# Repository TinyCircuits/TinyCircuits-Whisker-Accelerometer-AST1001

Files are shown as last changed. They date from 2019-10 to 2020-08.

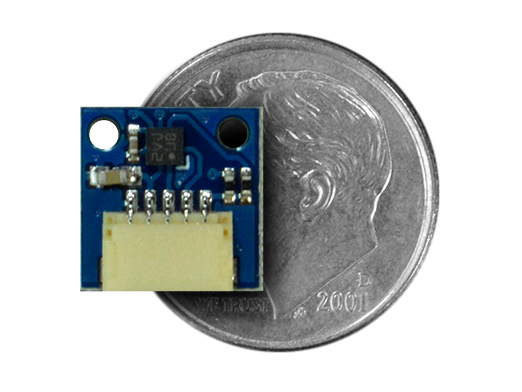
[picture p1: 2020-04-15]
images/AST1001-Product-Photo-03.png

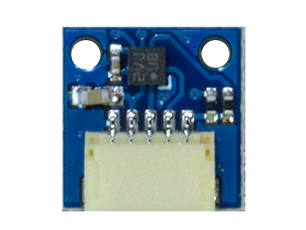
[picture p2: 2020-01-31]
images/AST1001-Learn-Photo-01.png

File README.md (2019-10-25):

# TinyCircuits Accelerometer Wireling Board
# AST1001 Rev1

The design files are located under design_files/ for the TinyCircuits ASD2205 Rev 2 PCB.  This is a Wireling board that has a BMA250 Accelerometer. 

Format is in Cadsoft Eagle format - Eagle version 6.2 was used for the original design.

For more infomation on this, check out the product page at TinyCircuits.com:  https://tinycircuits.com/products/microsd-tinyshield

# License:

Design by TinyCircuits.
All design files are released under the Creative Commons Attribution Share-Alike 3.0 License, see the following link for details: http://creativecommons.org/licenses/by-sa/3.0

All text above must be included in any redistribution or derived design

This project uses designs and concepts developed as part of the Arduino project and the LilyPad project.  The TinyCircuits design files themselves (schematics, PCB and libraries) are not directly derived from these works' design files and have been created new, however the concepts and basic architecture behind the TinyDuino and TinyLily products are derived and we thank the hard work of the organizations below for their contributions to open-source hardware:
  
Original Arduino Uno Design by Team Arduino

LilyPad Arduino Design by Leah Buechley and Sparkfun Electronics

Please support the open-source hardware community

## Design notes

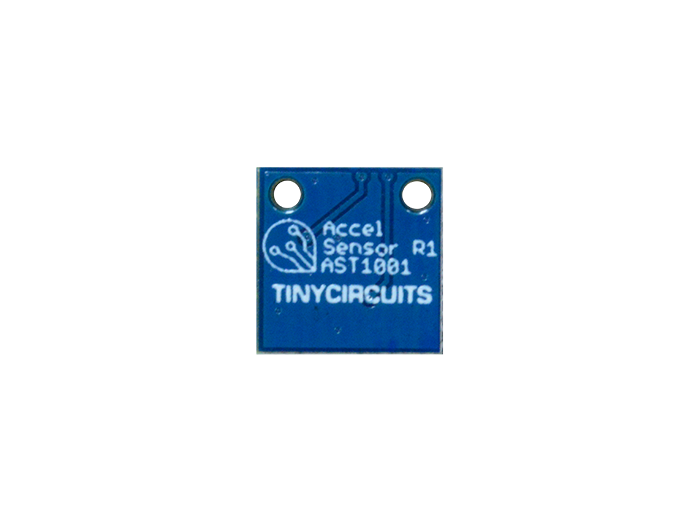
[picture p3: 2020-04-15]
images/AST1001-Product-Photo-02.png

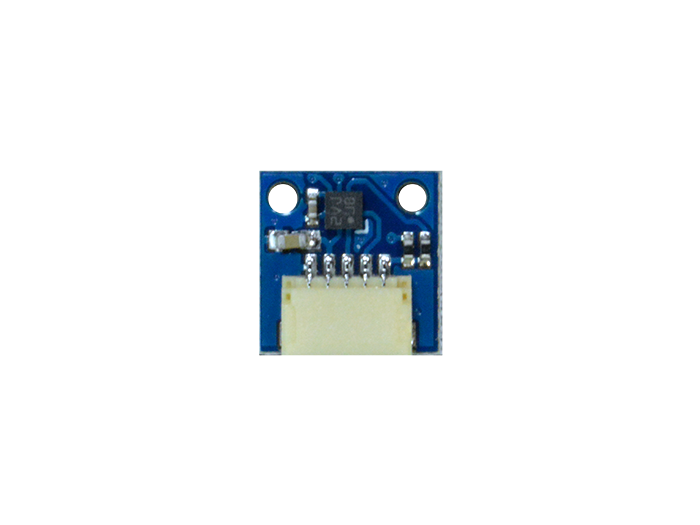
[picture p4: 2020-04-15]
images/AST1001-Product-Photo-01.png

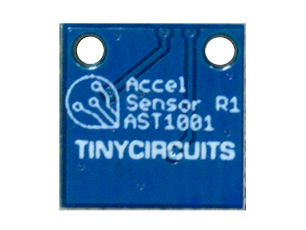
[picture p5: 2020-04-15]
images/AST1001-Learn-Photo-02.png

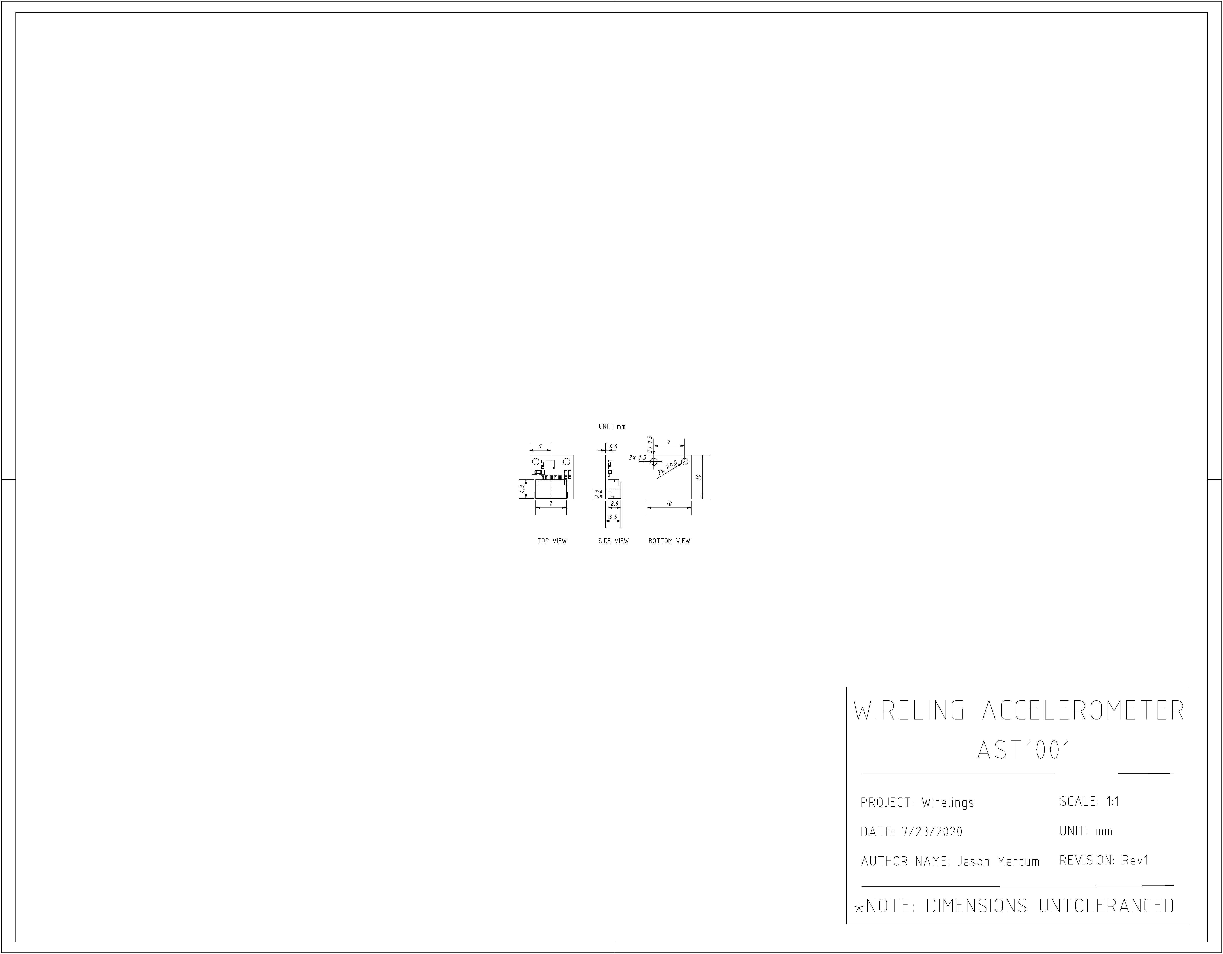
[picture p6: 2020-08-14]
cad/Wireling_ACCELEROMETER_AST1001_REV1-DETAILED_DRAWING-PNG.png

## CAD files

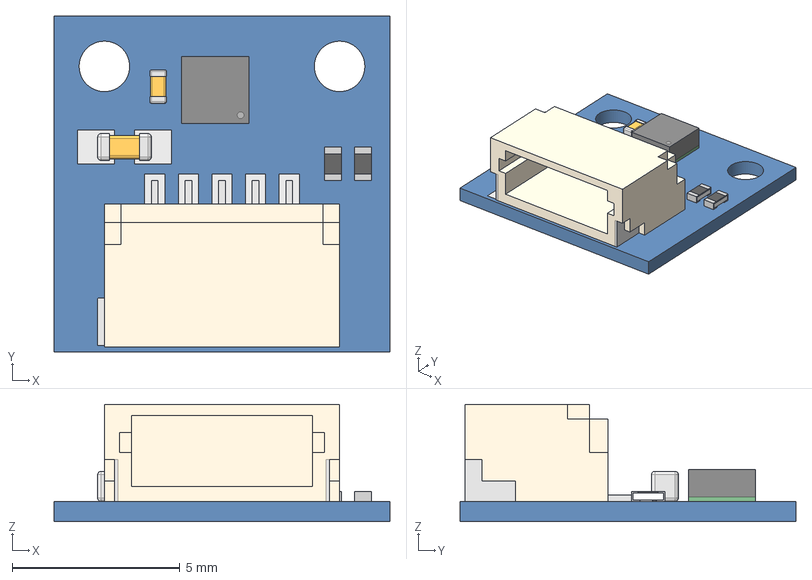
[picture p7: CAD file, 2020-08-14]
cad/Wireling_ACCELEROMETER_AST1001_REV1-STEP.step
10.0 x 10.0 x 3.50 mm

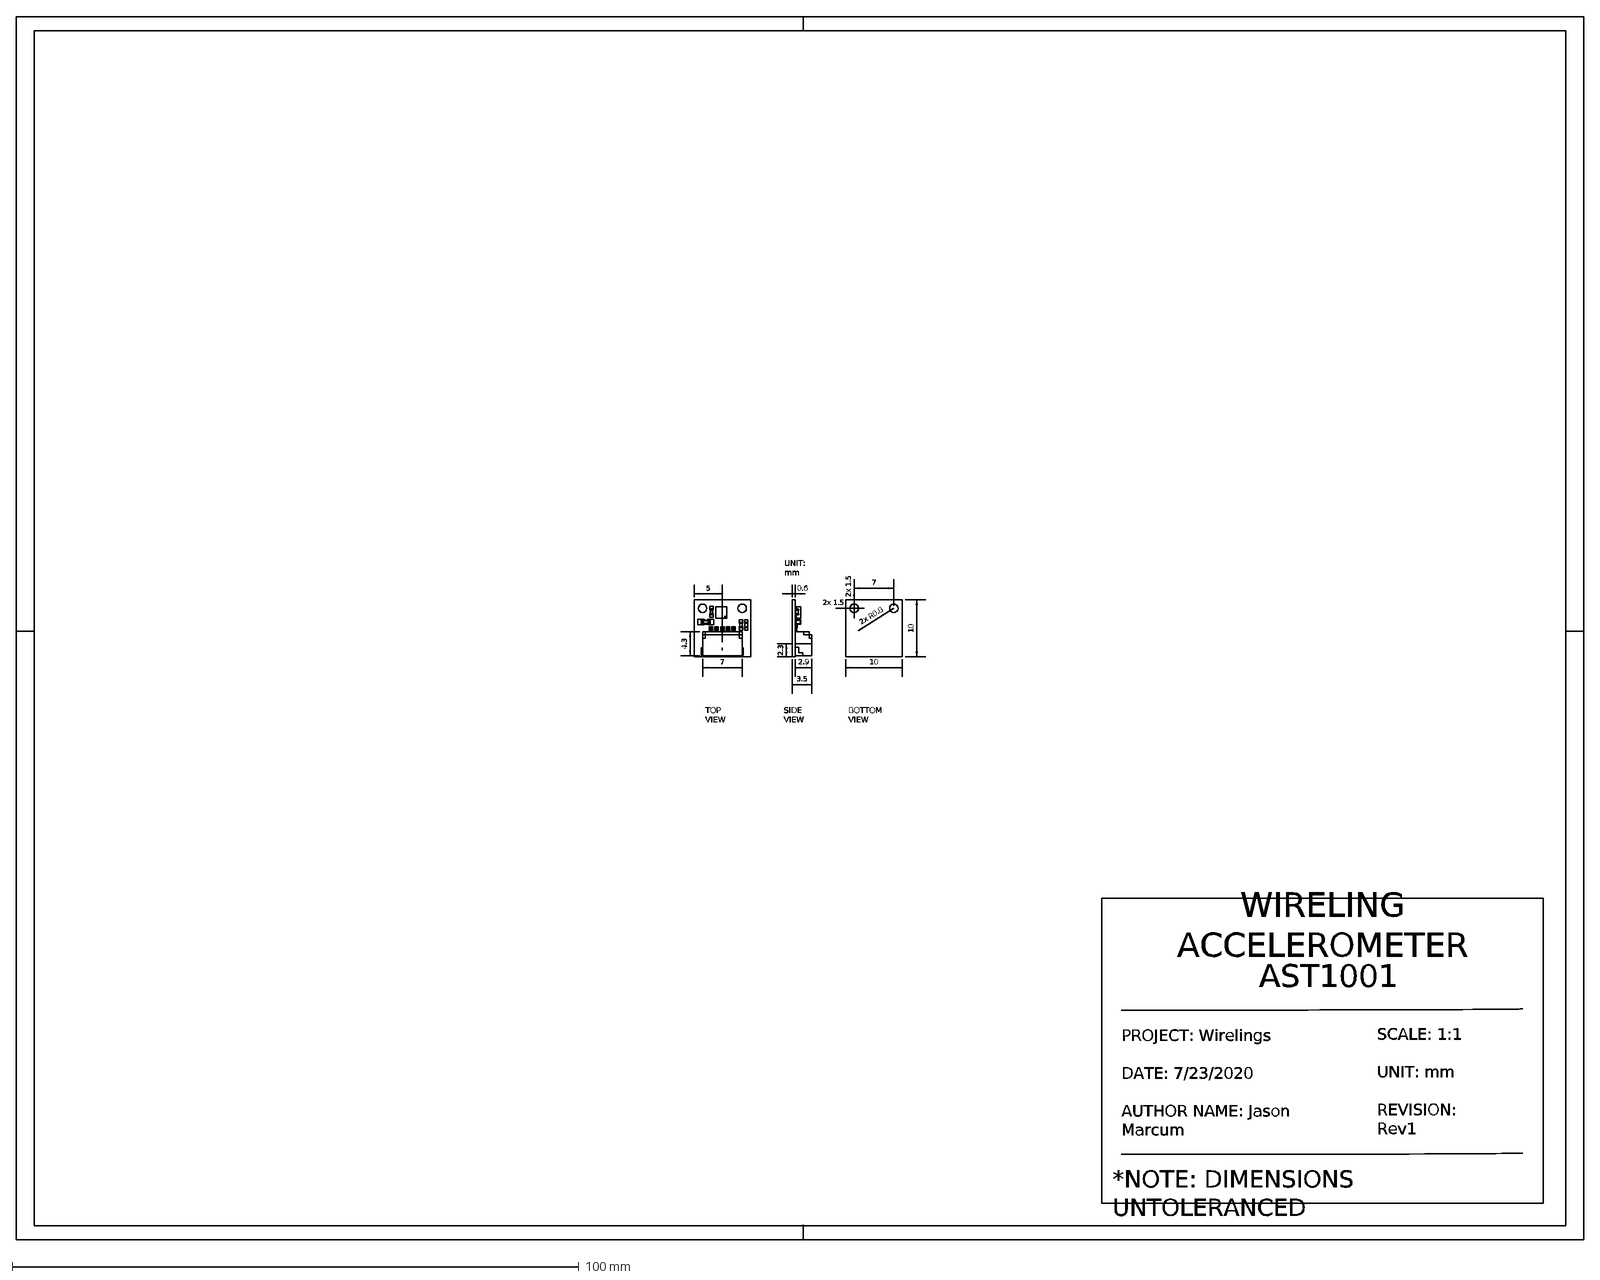
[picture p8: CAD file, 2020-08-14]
cad/Wireling_ACCELEROMETER_AST1001_REV1-DETAILED_DRAWING-DXF.dxf
*NOTE: DIMENSIONS UNTOLERANCED
WIRELING ACCELEROMETER
AST1001
SCALE: 1:1 UNIT: mm REVISION: Rev1
UNIT: mm
TOP VIEW
SIDE VIEW
BOTTOM VIEW
7
4.3
5
2.9
3.5
0.6
2.3
2x 1.5
2x R0.8
10
PROJECT: Wirelings DATE: 7/23/2020 AUTHOR NAME: Jason Marcum

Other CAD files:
cad/Wireling_ACCELEROMETER_AST1001_REV1-IGES.iges
cad/Wireling_ACCELEROMETER_AST1001_REV1-STL.stl

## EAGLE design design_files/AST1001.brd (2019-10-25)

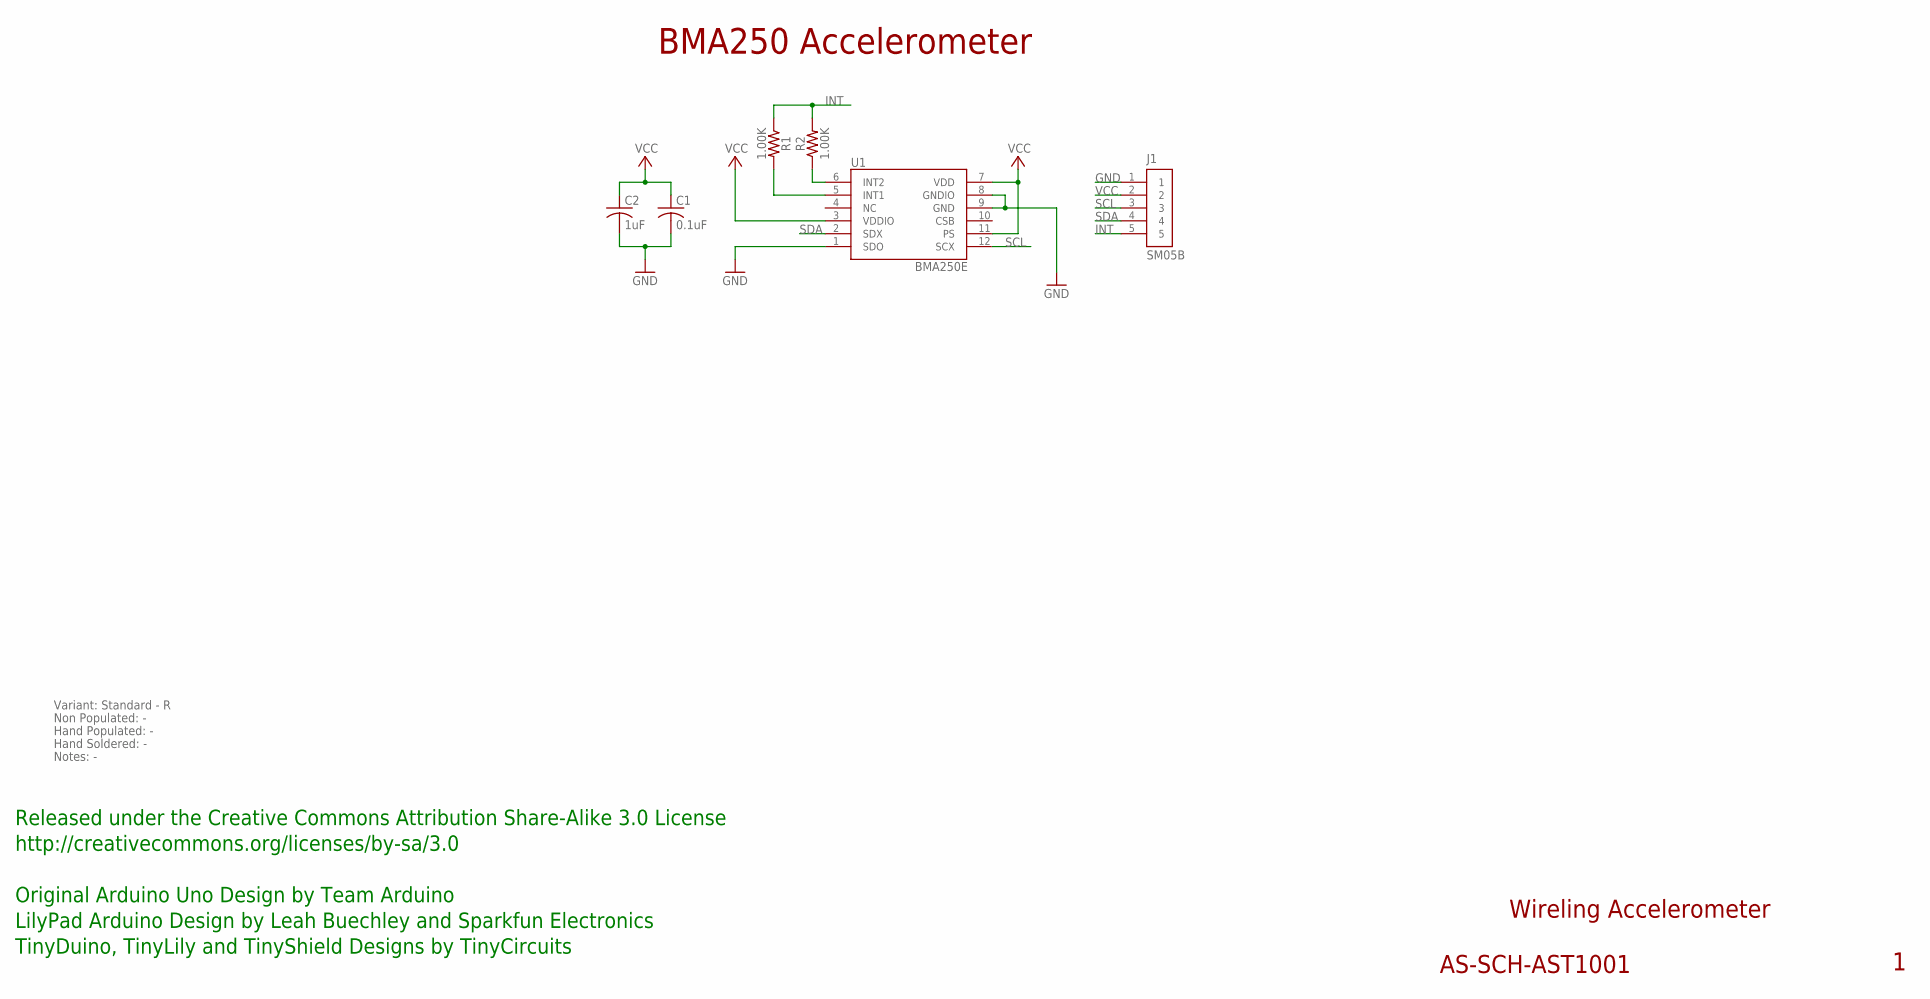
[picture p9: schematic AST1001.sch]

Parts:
C1: 0.1uF; C0402
C2: 1uF; C0603; PARTNO AS-ITM-00410
J1: SM05B; JST_SH_5X1_EDGE
R1, R2: 1.00K; 0402; PARTNO AS-ITM-00003
U1: BMA250E; 3-AXIS_ACCELEROMETER

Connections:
GND: C1.2, C2.2, J1.1, U1.1 (SDO), U1.8 (GNDIO), U1.9 (GND)
INT: J1.5, R1.1, R2.2
unnamed: R1.2, U1.5 (INT1)
unnamed: R2.1, U1.6 (INT2)
SCL: J1.3, U1.12 (SCX)
SDA: J1.4, U1.2 (SDX)
VCC: C1.1, C2.1, J1.2, U1.3 (VDDIO), U1.7 (VDD), U1.11 (PS)

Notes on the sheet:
Wireling Accelerometer
AS-SCH-AST1001
BMA250 Accelerometer
Released under the Creative Commons Attribution Share-Alike 3.0 License
http://creativecommons.org/licenses/by-sa/3.0
Original Arduino Uno Design by Team Arduino
TinyDuino, TinyLily and TinyShield Designs by TinyCircuits
LilyPad Arduino Design by Leah Buechley and Sparkfun Electronics
Non Populated: -
Hand Populated: -
Hand Soldered: -
Variant: Standard - R
Notes: -

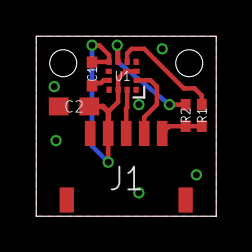
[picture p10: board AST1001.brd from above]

Board: 2 copper layers, 10.0 x 10.0 mm, 7 parts (0 on the bottom side), 7 nets.

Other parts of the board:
U$1: DOCFIELD-TINYCIRCUITS-PCB

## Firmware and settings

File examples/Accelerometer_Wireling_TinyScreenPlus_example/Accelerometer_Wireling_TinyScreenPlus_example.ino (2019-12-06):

/*************************************************************************
 * Accelerometer BMA250 Wireling Tutorial:
 * This example program will show the basic method of printing out the 
 * accelerometer values from the BMA250 to the TinyScreen+, Serial Monitor, 
 * and the Serial Plotter
 * 
 * Hardware by: TinyCircuits
 * Code by: Laveréna Wienclaw for TinyCircuits
 *
 * Initiated: 11/29/2017 
 * Updated: 12/06/2019
 ************************************************************************/
 
#include <Wire.h>         // For I2C communication with sensor
#include <TinyScreen.h>   // For interfacing with the TinyScreen+
#include <Wireling.h>     // For interfacing with Wirelings
#include "BMA250.h"       // For interfacing with the accel. sensor

// TinyScreen+ variables
TinyScreen display = TinyScreen(TinyScreenPlus);
int background = TS_8b_Black;

// Accelerometer sensor variables for the sensor and its values
BMA250 acccel_sensor;
int x, y, z, temp;

// Make Serial Monitor compatible for all TinyCircuits processors
#if defined(ARDUINO_ARCH_AVR)
  #define SerialMonitorInterface Serial
#elif defined(ARDUINO_ARCH_SAMD)
  #define SerialMonitorInterface SerialUSB
#endif

void setup() {
  SerialMonitorInterface.begin(115200);
  Wire.begin();

  // Initialize Wireling
  Wireling.begin();
  Wireling.selectPort(0); 

  // Setup and style for TinyScreen+
  display.begin();
  display.setFlip(true);
  display.setBrightness(15);
  display.setFont(thinPixel7_10ptFontInfo);
  display.fontColor(TS_8b_White, background);

  // Just displaying a quick message to show program has been uploaded
  // The following three lines can be removed
  display.setCursor(0, 0);
  display.print("Initializing BMA...");
  delay(1000);

  // Set the cursor to the following coordinates before it prints "BMA250 Test" 
  acccel_sensor.begin(BMA250_range_2g, BMA250_update_time_64ms); // Sets up the BMA250 acccel_sensorerometer
  display.clearScreen();
}

void loop() {
  // This will make the screen look a little unsteady but is needed in order
  // to clear old values 
  display.clearScreen();
  
  acccel_sensor.read();//This function gets new data from the acccelerometer

  // Get the acceleration values from the sensor and store them into local variables
  // (Makes reading the rest of the program easier)
  x = acccel_sensor.X;
  y = acccel_sensor.Y;
  z = acccel_sensor.Z;
  temp = ((acccel_sensor.rawTemp * 0.5) + 24.0, 1);

 // If the BMA250 is not found, nor connected correctly, these values will be produced
 // by the sensor 
  if (x == -1 && y == -1 && z == -1) {
    // Print error message to Serial Monitor
    SerialMonitorInterface.print("ERROR! NO BMA250 DETECTED!");

    // Display an error on the TinyScreen+
    display.setCursor(0, 48);
    display.fontColor(TS_8b_Red, background);
    display.print("ERROR! NO BMA250 Sensor");
    display.fontColor(TS_8b_White, background);
    delay(100);
  }
  else { // if we have correct sensor readings: 
    showSerial();                 //Print to Serial Monitor 
    showDisplay(x, y, z, temp);   //Display on TinyScreen 
  }

  // The BMA250 can only poll new sensor values every 64ms, so this delay
  // will ensure that we can continue to read values
  delay(250);
  // ***Without the delay, there would not be any sensor output*** 
}


// Prints the sensor values to the Serial Monitor (found under 'Tools')
void showSerial() {
  SerialMonitorInterface.print("X = ");
  SerialMonitorInterface.print(x);
  
  SerialMonitorInterface.print("  Y = ");
  SerialMonitorInterface.print(y);
  
  SerialMonitorInterface.print("  Z = ");
  SerialMonitorInterface.print(z);
  
  SerialMonitorInterface.print("  Temperature(C) = ");
  SerialMonitorInterface.println((acccel_sensor.rawTemp * 0.5) + 24.0, 1);
}

//Displays sensor data on the TinyScreen+ 
void showDisplay(int a, int b, int c, int d) {
  display.setCursor(0, 0);
  display.print("BMA250 Readings:");
  
  display.setCursor(0, 12);
  display.print("X = ");
  display.print(a);

  display.setCursor(0, 24);
  display.print("Y = ");
  display.print(b);

  display.setCursor(0, 36);
  display.print("Z = ");
  display.print(c);
  
  display.setCursor(0, 48);
  display.print("T = ");
  display.print(d);
}

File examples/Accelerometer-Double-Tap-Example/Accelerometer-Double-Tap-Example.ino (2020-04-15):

//-----------------------------------------------------------------
// TinyCircuits BMA250 Double Tap Example
// This example is mutually exclusive from other distributions of the
// TinyCircuits BMA250 examples.
//
// Written by Ben Rose for TinyCircuits, http://TinyCircuits.com
// Last Updated: January 2020
//-----------------------------------------------------------------

#include <Wire.h>
#include "BMA250.h"
#include <Wireling.h>

// Universal Serial Monitor Config
#if defined (ARDUINO_ARCH_AVR)
#define SerialMonitorInterface Serial
#elif defined(ARDUINO_ARCH_SAMD)
#define SerialMonitorInterface SerialUSB
#endif

BMA250 accel;

void setup(void) {
  Wireling.begin();
  SerialMonitorInterface.begin(115200);
  delay(100);
  Wire.begin();
  accel.begin(BMA250_range_8g, BMA250_update_time_4ms);
  accel.doubleTapInit();
  accel.read();
  Wireling.selectPort(0);
}


void loop() {
  accel.read();
//  SerialMonitorInterface.print("x: ");
//  SerialMonitorInterface.print(accel.X);
//  SerialMonitorInterface.print(", y: ");
//  SerialMonitorInterface.print(accel.Y);
//  SerialMonitorInterface.print(", z:");
//  SerialMonitorInterface.print(accel.Z);
//  SerialMonitorInterface.print(",  t: ");
//  SerialMonitorInterface.print(accel.rawTemp / 2 + 24);
//  SerialMonitorInterface.println("degC");

  if (accel.doubleTap) {
    SerialMonitorInterface.print(millis());
    SerialMonitorInterface.println("Double tap detected!");
    accel.clearInterrupt();
  }
}
